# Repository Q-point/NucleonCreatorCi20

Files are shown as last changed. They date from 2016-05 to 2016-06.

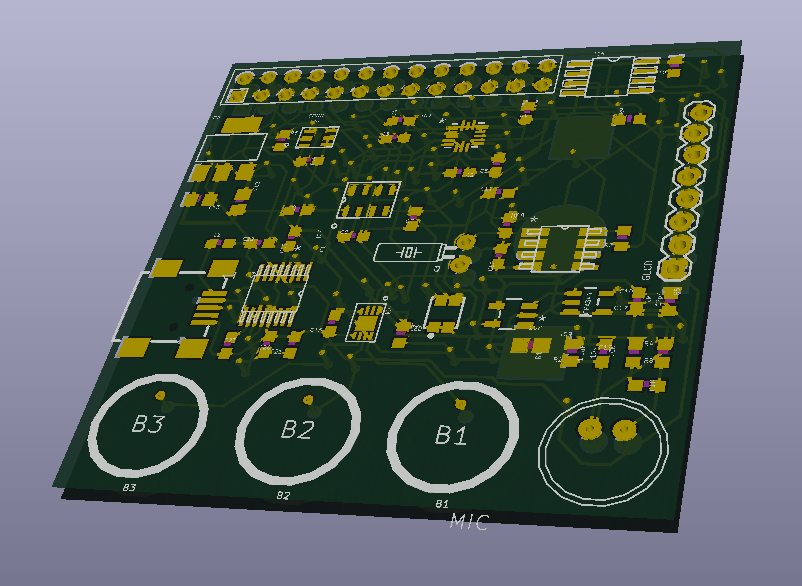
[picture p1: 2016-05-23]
3D_board.png

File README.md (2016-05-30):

    This program is free software: you can redistribute it and/or modify
    it under the terms of the GNU General Public License as published by
    the Free Software Foundation, either version 3 of the License, or
    (at your option) any later version.

    This program is distributed in the hope that it will be useful,
    but WITHOUT ANY WARRANTY; without even the implied warranty of
    MERCHANTABILITY or FITNESS FOR A PARTICULAR PURPOSE.  See the
    GNU General Public License for more details.

    You should have received a copy of the GNU General Public License
    along with this program.  If not, see <http://www.gnu.org/licenses/>.

# NucleonCreatorCi20

This folder contains the hardware design for the Nucelon Ci20 Creator shield and the accompanying Python files and example
programs.

refer to the project page at https://www.hackster.io/dhq/skynet-node

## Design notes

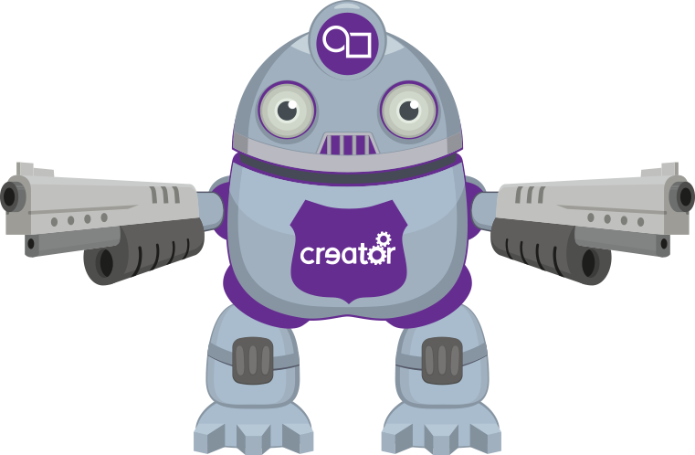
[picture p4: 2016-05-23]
Python_Drivers/S6D02A1A01_Display/Terminator.png

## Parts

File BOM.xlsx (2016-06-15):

BOM for Nucleon Shield.
Manufacturer ID | Designators | Description | Newark | Quantity
Power
NCP1117ST33T3G | IC2 | IC, LDO REGULATOR, 800mA, 3.3V | 67H7013 | 1
CC0805ZKY5V6BB106 | C12,C13 | CERAMIC, 10UF, 10V, Y5V, +80, -20%, 0805 | 68R4928 | 2
Altimeter
MPL3115A2 | IC7 | MINI I2C DIGITAL BAROMETER, 50KPA to 100KPA, LGA | 48T4344 | 1
CC0603KRX7R8BB104 | C6,C8 | CAPACITOR CERAMIC, 0.1UF, 25V, X7R, 10%, 0603 | 68R4780 | 2
C1608X5R1A106M080AC | C7 | CAPACITOR CERAMIC, 10UF, 10V, X5R, 20%, 0603 | 48T2910 | 1
Accelerometer
FXOS8700CQR1 | IC3 | 6-Axis Sensor accelerometer and magnetometer | 47W8598 | 1
CC0603KRX7R8BB104 | C1,C2,C3,C5 | CAPACITOR CERAMIC, 0.1UF, 25V, X7R, 10%, 0603 | 68R4780 | 4
MC0603X475K100CT | C4 | CAP, MLCC, X5R, 4.7UF, 10V, 0603 | 06X6198 | 1
RGB LED
CLVBA-FKA-CAEDH8BBB7A363 | LED | R 320mcd, G 500mcd, B 160mcd | 83T3705 | 1
APDS-9300-020 | IC5 | APDS-9300-020 AMBIENT LIGHT PHOTO SENSOR, DIGITAL | 97M3935 | 1
CC0603KRX7R8BB104 | C14 | CAPACITOR CERAMIC, 0.1UF, 25V, X7R, 10%, 0603 | 68R4780 | 1
RC0603JR-0710KL | R6 | RESISTOR, RC21 0603 10K | 98K7286 | 1
Memory Module
S25FL204K0TMFI040 | IC6 | MEMORY, FLASH NOR, 4MBIT, SOIC-8 | 45W4064 | 1
MC0603SAF4701T5E | R9,R10 | RESISTOR, THICK FILM, 4.7KOHM, 100mW, 1% | 79M5975 | 2
ADC
ADC081c027 | IC9 | IC, 8BIT ADC, I2C, SAR, TSOT23-6 | 47T4601 | 1
MCKPCM-97H45P-40DB-4808 | MIC | Omnidirectional 100Hz 16kHz 2V | 25R0618 | 1
OPA344NA/250G4 | IC10 | OP AMP, CMOS LOW POWER RRI/O, 344 | 13M5179 | 1
RC0603JR-0710KL | R1,R2,R4 | RESISTOR, RC21 0603 10K | 98K7286 | 3
MC0063W060311M | R5 | RESISTOR, 1M, 0.063W, 1%, 0603 | 94W5623 | 1
C0603C120J5GACTU | C17 | CAPACITOR CERAMIC 12PF 50V, C0G, 5%, 0603 | 19C1214 | 1
MC0603X475K100CT | C18 | CAP, MLCC, X5R, 4.7UF, 10V, 0603 | 06X6198 | 1
CC0603KRX5R6BB105 | C19 | CAPACITOR CERAMIC, 1UF, 10V, X5R, 10%, 0603 | 68R4757 | 1
CRCW06032K20FKEB | R8 | RESISTOR THICK FILM, 2.2KOHM, 100mW, ±1% | 48P8511 | 1
Capacitive Buttons
CAP1203-1-AC3-TR | IC4 | 3 Channel capacitve touch I2C controller | 19X2403 | 1
CC0603KRX7R8BB104 | C15 | CAPACITOR CERAMIC, 0.1UF, 25V, X7R, 10%, 0603 | 68R4780 | 1
CC0603KRX5R6BB105 | C16 | CAPACITOR CERAMIC, 1UF, 10V, X5R, 10%, 0603 | 68R4757 | 1
RC0603JR-0710KL | R7 | RESISTOR, RC21 0603 10K | 98K7286 | 1
USB interface
FT230XS-U | IC1 | IC USB SERIAL BASIC UART 16SSOP | 83T7087 | 1
USB2066-05-RBHM-15-STB-00-00-A | USB | CONN USB MINI B R/A SMD | 69R4880 | 1
CC0603KRX7R8BB104 | C20,23 | CAPACITOR CERAMIC, 0.1UF, 25V, X7R, 10%, 0603 | 68R4780 | 2
VJ0603Y103KXACW1BC | C21 | CAP MLCC, 0.01UF, 50V, X7R, 10%, 0603 | 52X6481 | 1
C2012X7R1C475K125AB | C22 | CAP, MLCC, X7R, 4.7UF, 16V, 0805 | 05X9887 | 1
MF-FSMF050X-2 | L2 | SMD fuse 500mA TRP Curr 1A 0.8ohm | 87W5964 | 1
RTC module
MCP7940M-I/SN | IC8 | MICROCHIP MCP7940M-I/SN REAL TIME CLOCK I2C, SOIC-8 | 79T6324 | 1
Bat_3078 | BATT | BATTERY CONTACT, POS, 20MM CELL, SURFACE MT | 25T0431 | 1
MCRJ332768F1220HOW | Q1 | CRYSTAL 32.768KHZ 12.5PF THRU HOLE | 56P2824 | 1
CC0603KRX7R8BB104 | C11 | CAPACITOR CERAMIC, 0.1UF, 25V, X7R, 10%, 0603 | 68R4780 | 1
MC0603N9R0D500CT | C10 | CAPACITOR CERAMIC 9PF 50V, C0G/NP0, 0.5pF, 0603 | 06R5220 | 1
MC0603N7R0D500CT | C9 | CAPACITOR CERAMIC 7PF 50V, C0G/NP0, 0.5pF, 0603 | 06R5210 | 1
RC0603JR-0710KL | R3 | RESISTOR, RC21 0603 10K | 98K7286 | 2
CR2032 SANYO | CR2032 | LITHIUM BATTERY, 3V, COIN CELL | 01H9520 | 1
Connectors
1-215307-3 | CONN | SOCKET, VERTICAL, 2ROW, 26WAY | 98K4870 | 1
BG095-08-A-N-D | GLCD | BOARD-BOARD CONNECTOR SOCKET, 8WAY, 1ROW | 67R8591 | 1

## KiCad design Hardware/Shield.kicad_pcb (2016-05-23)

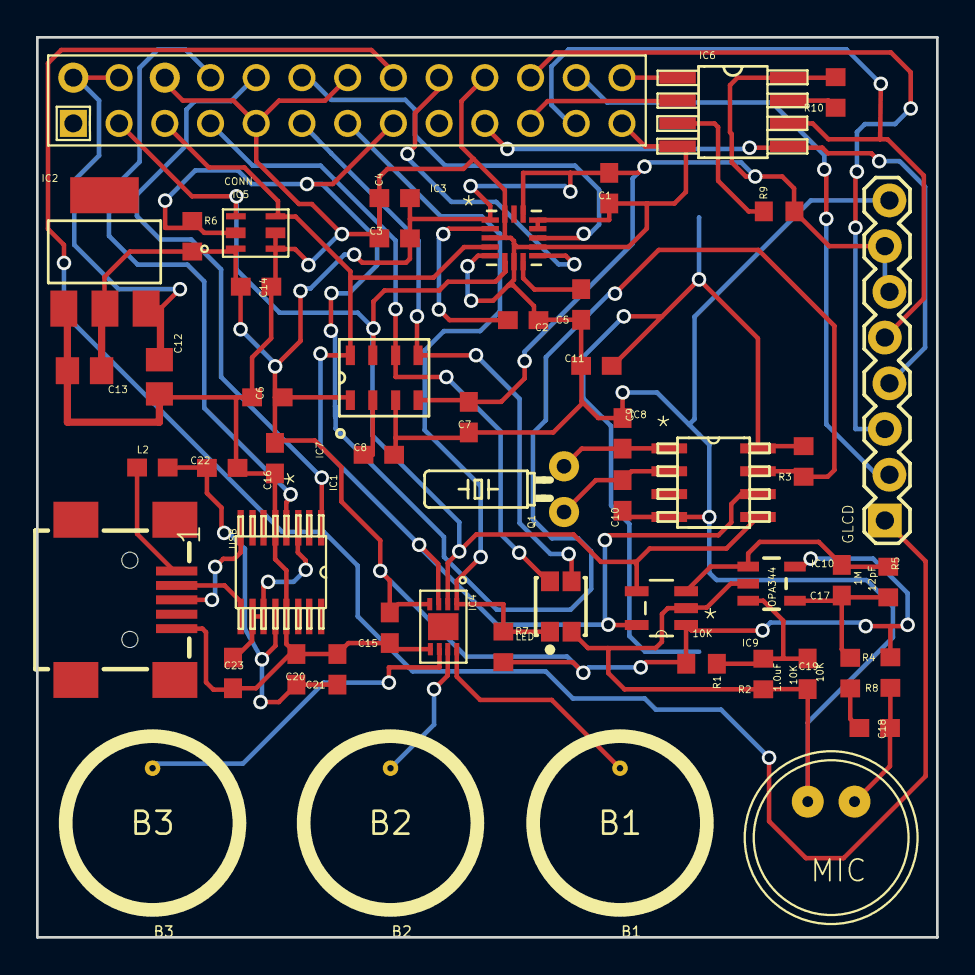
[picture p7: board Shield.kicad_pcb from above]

Board: 2 copper layers, 50.0 x 50.0 mm, 56 parts (0 on the bottom side), 38 nets.

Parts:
B1: B1; BUTTON_PASSIVE_8MM
B2: B2; BUTTON_PASSIVE_8MM
B3: B3; BUTTON_PASSIVE_8MM
BATT: BATTERY_2032; BATT2032
C1, C2, C3, C5, C11, C14, C15, C20, C23: 0.1uF; C0603
C4, C18, C22: 4.7uF; C0603
C6, C8: 100nF; C0603
C7: 10uF; C0603
C9, C10: 12.5pF; C0603
C12, C13: 10uF; C0805
C16: 1uF; C0603
C17: 12pF; C0603
C19: 1.0uF; C0603
C21: 10nF; C0603
CE: CE_MARK5MM; CE_5MM
CONN: RASPBERRY-PI_REV1
GLCD: 1X08_LOCK
IC1: FT230XS; SOP63P600X175-16N
IC2: REG1117; SOT223
IC3: FXOS8700CQR1; QFN50P300X300X120-16N
IC4: CAP1203; TDFN-8
IC5: APDS-9300; CHIP_LED
IC6: S25FL; SO-8
IC7: MPL3115A2; DFN300X500X120-8N
IC8: MCP79400-I/SN; SOIC127P600X175-8N
IC9: MCP3221A5T-I/OT; SOT95P270X145-5N
IC10: OPA344; SOT23-5
L2: 100mA+ ferrite bead; 0603
LED: RGB; RGBLED_PLCC4
MIC: M; 9.7ELECTRET
Q1: 32Khz; TC26H
R1, R2, R4: 10K; R0603
R3, R6, R7: 10k; R0603
R5: 1M; R0603
R8: 2.2K; R0603
R9, R10: 4.7k; R0603
ROHS: ROSH_GARBAGE; ROHS_GARBAGE_5MM
USB: CONN_USB; CONN_USB_MINI-B

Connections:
5V: C12.1, CONN.2, CONN.4, IC2.3
5V+: C20.1, C21.1, C22.1, IC1.12, L2.2
ALERT: CONN.13, IC4.1, LED.1, R7.1
AUD: C17.2, IC9.3, IC10.1, R5.1
A_INT1: CONN.12, IC3.11
A_INT2: CONN.18, IC3.9
BUS_PWR: L2.1, USB.VUSB
B_INT1: CONN.7, IC7.6, LED.4
B_INT2: CONN.11, IC7.5, LED.3
CS_MEM: CONN.26, IC6.1
CS_TFT: CONN.24, GLCD.2
GND: BATT.V-, C1.1, C2.1, C3.1, C4.1, C5.1, C6.1, C7.1, C8.2, C9.1, C10.1, C11.1, C12.2, C13.2, C14.1, C15.1, C16.1, C19.2, C20.2, C21.2, C22.2, C23.2, CONN.6, CONN.9, CONN.14, CONN.20, CONN.25, GLCD.8, IC1.5, IC1.13, IC2.1, IC3.3, IC3.5, IC3.7, IC3.10, IC3.12, IC3.13, IC3.16, IC4.5, IC5.2, IC5.3, IC6.4, IC7.3, IC8.4, IC9.2, IC10.2, LED.2, MIC.-, R2.1, USB.GND
INT_LUX: CONN.15, IC5.6, IC8.7, R3.1, R6.1
MISO: CONN.21, IC6.2
MOSI: CONN.19, GLCD.4, IC6.5
unnamed: C18.1, MIC.+, R8.1
unnamed: C17.1, IC10.4, R4.1, R5.2
unnamed: C2.2, IC3.2
unnamed: C8.1, IC7.2
unnamed: C5.2, IC3.8
unnamed: BATT.V1, BATT.V2, C11.2, IC8.8, R3.2
unnamed: C10.2, IC8.2, Q1.1
unnamed: C9.2, IC8.1, Q1.2
unnamed: C18.2, R4.2
unnamed: C19.1, IC10.3, R1.1, R2.2
unnamed: IC6.3, R9.1
unnamed: IC6.7, R10.1
unnamed: IC1.8, USB.D+
unnamed: IC1.9, USB.D-
unnamed: C23.1, IC1.3, IC1.10, IC1.11
RES: CONN.16, GLCD.1
RS: CONN.22, GLCD.3
RX: CONN.10, IC1.1
SCK: CONN.23, GLCD.5, IC6.6
SCL: CONN.5, IC3.4, IC4.3, IC5.4, IC7.8, IC8.6, IC9.5
SDA: CONN.3, IC3.6, IC4.2, IC5.5, IC7.7, IC8.5, IC9.4
TX: CONN.8, IC1.4
VDD: C1.2, C3.2, C4.2, C6.2, C7.2, C13.1, C14.2, C15.2, C16.2, GLCD.6, GLCD.7, IC2.2, IC3.1, IC3.14, IC4.4, IC5.1, IC6.8, IC7.1, IC7.4, IC9.1, IC10.5, R1.2, R6.2, R7.2, R8.2, R9.2, R10.2

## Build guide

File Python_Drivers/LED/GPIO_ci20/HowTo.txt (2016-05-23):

$ gcc -c -Wall -Werror -fpic ci20.c

$ gcc -shared -o libCi20GPIO.so ci20.o 

from ctypes import *
GPIO = CDLL("./libCi20GPIO.so")

GPIO.ci20ValidGPIO()
GPIO.setup()
GPIO.ci20DigitalRead(pin);
GPIO.ci20DigitalWrite(pin, value);
GPIO.ci20PinMode(pin,mode);

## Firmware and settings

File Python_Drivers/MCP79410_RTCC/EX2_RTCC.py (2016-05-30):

#!/usr/bin/python
import sys
import smbus
import time

import MCP79410RTCC as rtc

def main(argv):
	print "=== Real Time Clock and Calendar  ===" 
	print "*************************************" 

	RTC = rtc.MCP79410()			#create RTCC object

	userTime= rtc.RTCC_Struct(2,20,11,2,2,2,15)

	RTC.SetTime(userTime)

	while True: 
		rtcTime = RTC.GetTime() 			#get time
		tmr = "Time is: " + str(rtcTime.hour) + ":" + str(rtcTime.min)+ ":" + str(rtcTime.sec)  	#convert to string and print it
		print tmr
		dat = "Date is: " + str(rtcTime.year) + "/" + str(rtcTime.month)+ "/" + str(rtcTime.date)  	#convert to string and print it
		print dat	
		time.sleep(1)
		
if __name__ == '__main__':
    try:
        main(sys.argv[1:])
    except KeyboardInterrupt:
        print("")
		

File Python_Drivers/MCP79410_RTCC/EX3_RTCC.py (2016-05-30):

#!/usr/bin/python
import sys
import smbus
import time
import MCP79410RTCC as rtc

def main(argv):
	print "=== Real Time Clock Baackup Battery mode  ===" 
	print "*************************************" 

	RTC = rtc.MCP79410()			#create RTCC object

	if(RTC.IsVBatEnabled()):
		print "Battery mode Enabled.\r\n"
	else:
		print "Battery mode Disabled. Enabling ..\r\n"
		RTC.MCP79410_EnableVbat()
		
	powerDown_Time = RTC.GetPowerDownTime()
	print "Power down time: " + str(powerDown_Time.month) + ":" + str(powerDown_Time.date) + ":" + str(powerDown_Time.hour) + ":" + str(powerDown_Time.min)
		
	powerUp_Time = RTC.GetPowerUpTime()
	print "Power up time: " + str(powerUp_Time.month) + ":" + str(powerUp_Time.date) + ":" + str(powerUp_Time.hour) + ":" + str(powerUp_Time.min)
		
	if(RTC.CheckPowerFailure() == True):
		print "There was a power failure.\r\n"
	else:
		print "No power failure.\r\n"

	while True: 
		rtcTime = RTC.GetTime() 			#get time
		tmr = "Time is: " + str(rtcTime.hour) + ":" + str(rtcTime.min)+ ":" + str(rtcTime.sec)  	#convert to string and print it
		print tmr
		time.sleep(1)
		

if __name__ == '__main__':
    try:
        main(sys.argv[1:])
    except KeyboardInterrupt:
        print("")

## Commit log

2016-05-23 First Commit
    First commit of the Nucleon Shield hardware and Python examples for
    Creator Ci20
    [Shield-B.Adhes.gbr, Shield-B.CrtYd.gbr, Shield-B.Fab.gbr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]
2016-06-15 Added BOM to Hardware folder
    [BOM.xlsx]
2016-06-15 Added BOM for hardware schematics.
    [BOM.xlsx]

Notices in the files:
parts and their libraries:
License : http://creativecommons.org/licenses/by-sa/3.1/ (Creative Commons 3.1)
